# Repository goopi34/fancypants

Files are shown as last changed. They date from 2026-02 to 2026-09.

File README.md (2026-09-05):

# Fancypants


<br/>
A two-part system that uses an nRF52840 + VL53L0X time-of-flight sensor to control
sex toys through Intiface Engine. "Wave your hand" closer to the sensor for more
intensity, pull away to reduce it — or flip it around, or drive intensity by how
fast you're moving (see `mapping.mode` in [docs/middleware.md](docs/middleware.md)).

```mermaid
flowchart LR
    fw["<b>fancypants-nrf52</b><br/>Feather nRF52840<br/>+ VL53L0X sensor"]
    mw["<b>fancypants</b><br/>Rust middleware<br/>mapping + EMA"]
    engine["<b>Intiface Engine</b>"]
    toy(["toy"])
    fw -- "BLE<br/>range_mm + battery" --> mw
    mw -- "WebSocket<br/>intensity ScalarCmd" --> engine
    engine --> toy
```

## Quick start

Prebuilt binaries (firmware `.uf2` + Linux x86_64 middleware) are on the
[Releases page](../../releases) — download, flash, run. To build from source
you need `docker` (or `podman`) and `make`; everything builds in containers:

```bash
# 1. Build firmware + middleware
make

# 2. Flash the Feather: double-tap reset, then copy the UF2
#    (or `west flash` via SWD; `make flash` prints the details)
cp build/firmware/zephyr.uf2 /run/media/$USER/FTHR840BOOT/

# 3. Start Intiface Central with your toy connected, then run the middleware
#    (finds ./config.toml or ~/.config/fancypants/config.toml automatically,
#     and creates the latter on first run)
./build/middleware/fancypants
```

Move your hand near the sensor and enjoy.

## Documentation

- [Hardware & wiring](docs/hardware.md)
- [Building](docs/building.md) — build options, tests, manual (container-less) builds
- [Firmware](docs/firmware.md) — flashing, serial console, BLE protocol
- [Middleware](docs/middleware.md) — configuration, mapping modes, running
- [Troubleshooting](docs/troubleshooting.md)
- [Wearable design](wearable-design.md) — belt-mounted layout; printable
  enclosures in [enclosures/](enclosures/)

## License

MIT — see [LICENSE](LICENSE).

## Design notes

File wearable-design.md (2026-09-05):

# Fancypants Wearable Design Spec

## Overview

The fancypants hardware is worn as a belt-mounted system. The VL53L0X
rangefinder sits above the crotch facing outward, measuring the distance
to a partner's hand (or body). The Feather nRF52840 rides on the
hip opposite the belt clasp, powered by a 500mAh LiPo battery plugged directly into
the Feather's JST-PH connector.

## Layout

```
                  ┌─────────────┐
                  │  VL53L0X    │  ← sensor, facing outward
                  │  rangefinder│
                  └──────┬──────┘
                         │ I2C (4-wire: VIN, GND, SDA, SCL)
    ┌────────────────────┼────────────────────┐
    │                    │         BELT        │
    │  ┌──────────┐      │              ┌─────┐│
    │  │ Feather  │◄─────┘              │CLASP││
    │  │ nRF52840 │                     └─────┘│
    │  │ + LiPo   │                            │
    │  └──────────┘                            │
    └──────────────────────────────────────────┘
```

## Component Placement

### Belt

Standard belt or wide elastic waistband. The clasp sits on the right
hip (user's perspective, adjustable to preference). The belt carries
two components and the wiring between them.

### VL53L0X Sensor (front center)

- Mounted at belt line, centered above the crotch
- Sensor window faces directly outward (perpendicular to body)
- Field of view is 25° cone — aim straight out, not angled down
- Secured to belt with a small 3D-printed or sewn pouch
- Keep the sensor window unobstructed

### Feather nRF52840 + Battery (left hip)

- Mounted on the hip opposite the clasp
- Secured with a belt-mounted pouch, pocket, or velcro holster
- The BLE antenna is internal to the Feather — no external antenna
  needed, and the hip position gives decent range in all directions

## Power

The Feather is powered by an Adafruit 500mAh 3.7V LiPo battery
(product 1578, ~$8) plugged into the onboard JST-PH connector.

- Runtime: ~15 hours at typical draw (~30mA average with BLE +
  sensor polling)
- The battery and Feather are compact enough to share a single
  belt pouch
- The Feather's onboard charger handles recharging — just plug
  USB into the Feather. The yellow CHG LED lights during charge,
  goes off when complete. Charge time is ~5 hours from dead.
- When USB is connected, the Feather hot-swaps to USB power and
  charges the LiPo simultaneously

**Buy from Adafruit** (or verify JST-PH polarity matches Adafruit
convention). Cheap batteries from Amazon frequently have reversed
polarity and will destroy the Feather's charging circuit.

Link: https://www.adafruit.com/product/1578

## Wiring Run

The only wiring that runs along the belt is the I2C connection between
the Feather (left hip) and the VL53L0X (front center). This is 4 wires:

| Wire  | Color (STEMMA QT convention) | Notes |
|---|---|---|
| VIN | Red | 3.3V from Feather  |
| GND | Black | Ground |
| SDA | Blue | I2C data |
| SCL | Yellow | I2C clock |

Wire run is approximately 20-30cm depending on waist size. Options:

- **STEMMA QT cable**: Easiest. Adafruit sells 200mm and 300mm lengths.
  Plug directly into the VL53L0X breakout. Solder or use a STEMMA QT
  adapter on the Feather end.
- **Ribbon cable**: Low profile, can be sewn flat against the belt
  interior. 4-conductor ribbon or individual silicone wires.
- **Sewn channels**: For a cleaner look, sew a fabric channel along
  the belt interior and thread the wires through it.

I2C is tolerant of this wire length at 100kHz (the default). No
additional pullups or buffering needed beyond what the VL53L0X breakout
provides.

## Future Improvements

- 3D-printed enclosure that clips directly to belt

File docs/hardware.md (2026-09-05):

# Hardware

## Parts

- **Adafruit Feather nRF52840 Express**
- **Adafruit VL53L0X Time-of-Flight sensor breakout** (I2C, 30-1200mm range)
- **LiPo battery** (optional, JST-PH connector on Feather)
- Any Buttplug-compatible toy + Intiface Central

## Wiring

If your VL53L0X has a STEMMA QT / Qwiic connector, just use the cable.
Otherwise:

| Feather | VL53L0X |
|---|---|
| 3V | VIN |
| GND | GND |
| SDA | SDA |
| SCL | SCL |

The Adafruit VL53L0X breakout includes I2C pullups and a voltage regulator,
so no additional components are needed.

## Wearing it

See [wearable-design.md](../wearable-design.md) for the belt-mounted layout,
battery choice, and wiring run. Printable enclosures (OpenSCAD source +
exported STLs) live in [enclosures/](../enclosures/).

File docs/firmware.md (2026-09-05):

# Firmware (fancypants-nrf52)

## Flash

**UF2 method (no programmer needed):**

1. Connect Feather to USB
2. Double-tap the reset button — `FTHR840BOOT` drive appears
3. Copy the UF2 file:

```bash
cp build/firmware/zephyr.uf2 /run/media/$USER/FTHR840BOOT/
# (or wherever the drive mounts on your system)
```

**SWD method:**

```bash
west flash
```

## Verify

Connect to the USB serial console:

```bash
# Find the USB CDC ACM device
ls /dev/ttyACM*

# Connect (115200 baud, though CDC ACM ignores baud rate)
picocom /dev/ttyACM0
# or
screen /dev/ttyACM0 115200
```

You should see:

```
[00:00:00.000,000] <inf> main: Fancypants nRF52 0.1.4 starting...
[00:00:00.050,000] <inf> main: VL53L0X sensor ready
[00:00:00.060,000] <inf> battery: Battery ADC initialized on AIN5
[00:00:00.070,000] <inf> range_svc: Range Service initialized
[00:00:00.200,000] <inf> main: Bluetooth initialized
[00:00:00.210,000] <inf> main: Advertising as "Fancypants"
```

## BLE Protocol

**Custom Range Service UUID:** `00000001-7272-6e67-6669-6e6465720000`

| Characteristic | UUID | Properties | Data |
|---|---|---|---|
| Range | ...0002... | Read, Notify  | uint16_t LE, distance in mm |
| Config | ...0003... | Read, Write | 8-byte struct (see below) |

**Config struct (8 bytes, little-endian):**

| Offset | Type | Field |
|---|---|---|
| 0 | uint16_t | sample_interval_ms |
| 2 | uint16_t | notify_interval_ms |
| 4 | uint16_t | max_range_mm |
| 6 | uint16_t | min_range_mm |

Also exposes the standard **Battery Service (0x180F)**.

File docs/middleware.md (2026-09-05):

# Middleware (fancypants)

## Getting the binary

Either download the `fancypants-<version>-linux-x86_64.tar.gz` tarball from
the [Releases page](../../../releases) (binary + sample `config.toml`), or
build from source (see [building.md](building.md)) — the binary then lands in
`build/middleware/fancypants`.

## Prerequisites (runtime only)

- Linux (the only platform built and tested so far)
- Intiface Central running (https://intiface.com/#intiface-central)
- BlueZ

On Arch:

```bash
sudo pacman -S bluez bluez-utils
sudo systemctl enable --now bluetooth
```

## Configure

The middleware looks for its config in this order:

1. The path given with `-c PATH` (must exist)
2. `./config.toml` (current directory)
3. `$XDG_CONFIG_HOME/fancypants/config.toml` (usually `~/.config/fancypants/config.toml`)

If none is found, it writes a default config to
`~/.config/fancypants/config.toml`, prints where it put it, and runs with
those defaults — so on first run you get a commented config file to edit
without any extra steps. (The release tarball also ships a sample
`config.toml` next to the binary.)

`--generate-config` does the same thing explicitly (to `-c PATH` if given);
it refuses to overwrite an existing file.

```bash
# Edit as needed
$EDITOR ~/.config/fancypants/config.toml
```

Key settings:

- `mapping.mode` — what drives the intensity (see [Mapping modes](#mapping-modes))
- `mapping.invert = true` — closer = more intense (default, distance mode only)
- `mapping.min_range_mm` / `max_range_mm` — active zone
- `mapping.deadzone_mm` — pull away past this to turn off
- `mapping.smoothing` — 0.3 is a good default, increase for smoother response
- `ble.data_timeout_secs` — failsafe: if range data stops for this long, the toy
  is stopped and the middleware reconnects (0 disables)
- `buttplug.actuator_types` — which actuators to drive, with optional
  per-actuator settings (see below)

## Mapping modes

`mapping.mode` selects what the intensity follows:

- **`"distance"`** (default) — intensity follows the current reading, mapped
  across the `min_range_mm`–`max_range_mm` window. With `invert = true`
  closer means more intense; with `invert = false` further means more
  intense.
- **`"velocity"`** — intensity follows how *fast* the distance is changing,
  regardless of direction: wave or move quickly for more intensity, hold
  still for none. `max_speed_mm_s` sets the speed that maps to full
  intensity (default 500; slow hand movement is roughly 100-300mm/s, a fast
  wave ~1000mm/s). `invert` and the range window are ignored in this mode.

In both modes, readings beyond `deadzone_mm` produce zero intensity, and
`smoothing` applies to the result. In velocity mode a little extra smoothing
(0.4-0.6) helps, since speed estimates are inherently jumpier than distance
readings.

## Per-actuator configuration

Toys can have multiple actuators of different types (e.g. a vibrator plus an
oscillating arm). `buttplug.actuator_types` lists which types to drive; each
entry is either a plain type name or a table with per-actuator settings:

```toml
[buttplug]
server_address = "ws://127.0.0.1:12345"
actuator_types = [
    # Full-range vibration following the sensor
    "Vibrate",
    # Oscillation capped at 60%, pulsing on/off twice a second while active
    { type = "Oscillate", min_intensity = 0.2, max_intensity = 0.6, pattern = "pulse", pulse_hz = 2.0 },
]
```

Supported types: `Vibrate`, `Rotate`, `Oscillate`, `Constrict`, `Inflate`,
`Position`. Settings per actuator:

| Setting | Default | Meaning |
|---|---|---|
| `min_intensity` | 0.0 | Output when the mapped intensity is just above zero |
| `max_intensity` | 1.0 | Output when the mapped intensity is 1.0 |
| `pattern` | `constant` | `constant` follows the sensor; `pulse` gates it on/off |
| `pulse_hz` | 1.0 | Pulse frequency (only with `pattern = "pulse"`, max 10) |

Actuators on the toy whose type isn't listed are left off. If a toy has
several actuators of the same type, the nth entry of that type configures its
nth actuator, and extra actuators reuse the last entry of that type.

## Run

1. Start Intiface Central and ensure your toy is connected
2. Power on the Feather (USB or battery)
3. Run the middleware:

```bash
# Config is found automatically (./config.toml, then ~/.config/fancypants/)
./build/middleware/fancypants

# Or point at a specific config; with debug logging:
./build/middleware/fancypants -c myconfig.toml -l debug
```

## What happens

1. Middleware scans BLE for "Fancypants" device
2. Connects and subscribes to range notifications
3. Connects to Intiface Engine via websocket
4. Finds your toy
5. Maps distance → intensity and sends commands at ~20Hz

```
[INFO] Found device: Fancypants
[INFO] Connected to Intiface Engine at ws://127.0.0.1:12345
[INFO] Using device: We-Vibe Melt 2 (index 0)
[INFO] Running — move your hand near the sensor!
```

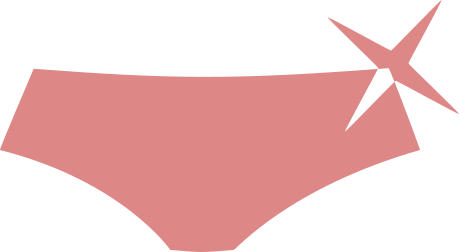
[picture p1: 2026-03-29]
fancypants.png

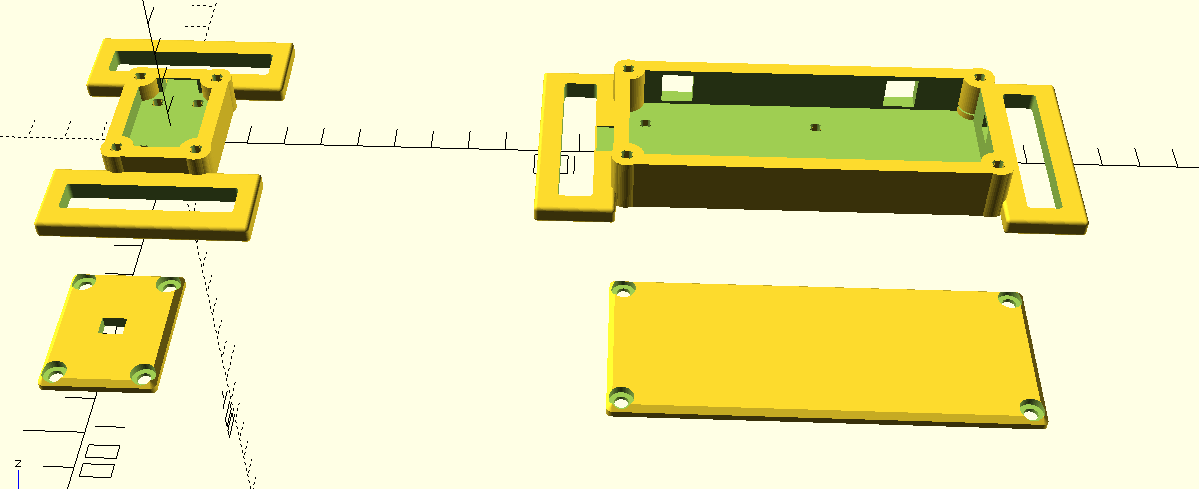
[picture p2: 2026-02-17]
enclosures/enclosures.png

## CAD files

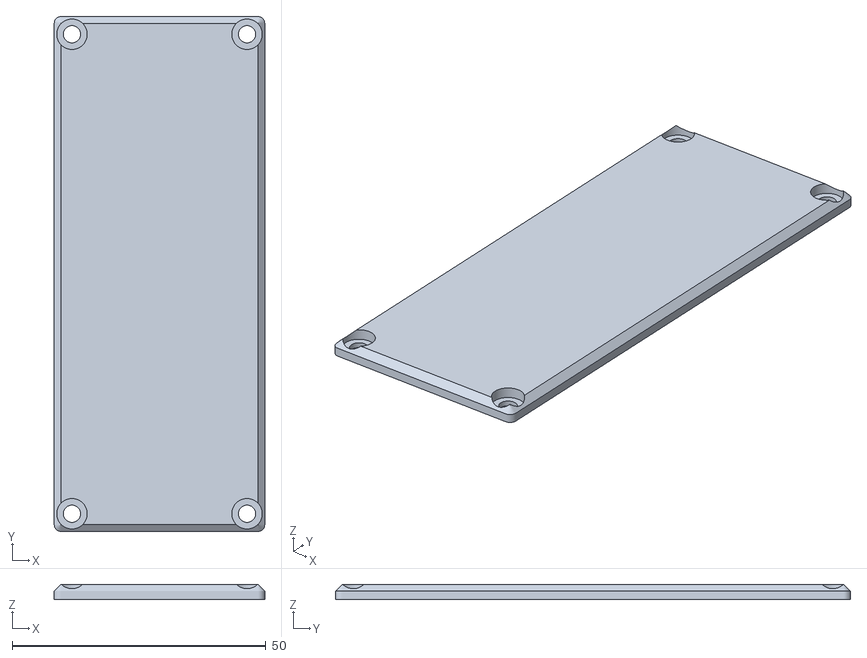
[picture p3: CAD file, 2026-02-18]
enclosures/hip_enclosure_top.stl
41.5 x 101.5 x 3.00

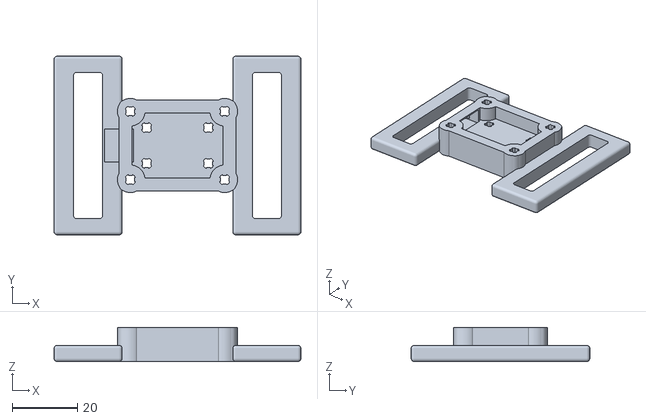
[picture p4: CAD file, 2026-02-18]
enclosures/front_enclosure_bottom.stl
76.0 x 55.0 x 10.5

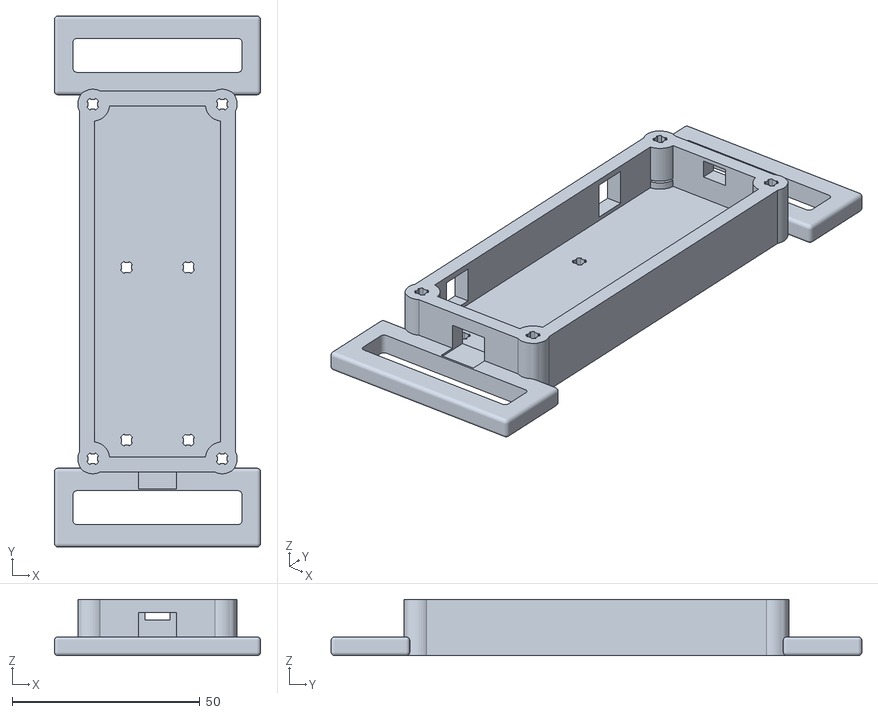
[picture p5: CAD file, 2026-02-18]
enclosures/hip_enclosure_bottom.stl
55.0 x 141.5 x 15.0

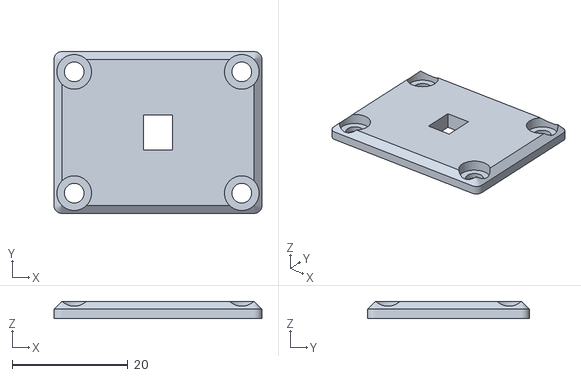
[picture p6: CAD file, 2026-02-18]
enclosures/front_enclosure_top.stl
36.0 x 28.0 x 3.00

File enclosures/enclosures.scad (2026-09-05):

// Belt-mounted wearable enclosure system for VL53L0X sensor + Feather nRF52840
// Two-part design: Front sensor enclosure + Hip controller enclosure
// Optimized for resin (DLP) printing

// ============================================================================
// GLOBAL PARAMETERS
// ============================================================================

$fn = 50;

// Common parameters
wall = 4;               // Wall thickness (resin-optimized)
clearance = 1.5;        // Component clearance
belt_width = 43;        // Belt width
belt_thickness = 7;     // Belt thickness at head
loop_clearance = 1;     // Extra clearance for belt in slots

// Screw boss parameters (3mm wood screws)
boss_od = 8;            // Outer diameter of screw boss (larger for ribbed interior)
boss_hole = 3.4;        // Oversized hole in boss (screw doesn't engage wall)
boss_rib_id = 2.6;      // Inner diameter at rib tips (screw bites into ribs)
boss_rib_count = 4;     // Number of grip ribs
boss_rib_width = 1.2;   // Angular width of each rib (mm at hole wall)
boss_clearance = 3.4;   // Clearance hole in lid for screw shaft
boss_counterbore_d = 6; // Counterbore diameter for screw head
boss_counterbore_depth = 2; // Counterbore depth in lid top

// Rounding
edge_r = 2;             // Fillet/round radius for edges and corners

// Belt tab parameters
tab_thickness = 5;      // Tab slab thickness
tab_wall = 5;           // Material bridge width flanking belt slot
tab_r = 1;              // Tab bottom edge rounding radius (kept small for printability)

// ============================================================================
// UTILITY MODULES
// ============================================================================

// Rounded rectangle 2D profile
module rounded_rect_2d(w, h, r) {
    offset(r) offset(-r) square([w, h], center=true);
}

// Box with rounded top edges only, perfectly flat bottom (for lids)
module rounded_box(w, h, d, r) {
    actual_r = min(r, d * 0.45);  // Clamp so it works for thin lids
    hull() {
        // Bottom: full-size rounded-corner rectangle, thin slab
        linear_extrude(height=0.01)
            rounded_rect_2d(w, h, actual_r);
        // Just below the top rounding: full-size
        translate([0, 0, d - actual_r])
            linear_extrude(height=0.01)
                rounded_rect_2d(w, h, actual_r);
        // Top: inset by actual_r on all sides, at full height
        translate([0, 0, d - 0.01])
            linear_extrude(height=0.01)
                rounded_rect_2d(w - 2*actual_r, h - 2*actual_r, 0.01);
    }
}

// Box with rounded vertical edges, flat top (for enclosure bodies)
module rounded_box_flat_top(w, h, d, r) {
    linear_extrude(height=d)
        rounded_rect_2d(w, h, r);
}

// Ribbed screw boss hole - oversized bore with inward ribs for thread grip
// Use in difference() to cut into a solid boss cylinder.
// Creates a hole_d bore with rib_count ribs protruding inward to rib_id.
module ribbed_boss_hole(hole_d, rib_id, rib_width, rib_count, h) {
    difference() {
        // Main oversized bore
        cylinder(d=hole_d, h=h);
        // Leave behind the ribs by subtracting the bore minus rib volumes
        // i.e., don't cut where the ribs are
        for(i = [0 : rib_count - 1]) {
            rotate([0, 0, i * (360 / rib_count)])
                translate([0, 0, -0.5])
                    linear_extrude(height=h + 1)
                        translate([rib_id/2, -rib_width/2])
                            square([(hole_d - rib_id)/2 + 0.1, rib_width]);
        }
    }
}

// Belt tab: rectangular body with ALL bottom edges and outer corners rounded
// Belt slot inner vertical edges also rounded for skin comfort
// Oriented: extends along +Y from origin, width along X
module belt_tab(tab_w, tab_l, tab_t, slot_w, slot_h, r) {
    difference() {
        // Start with a fully rounded shape via minkowski
        translate([0, tab_l/2, 0])
            minkowski() {
                translate([0, 0, tab_t/2])
                    cube([tab_w - 2*r, tab_l, tab_t - 2*r], center=true);
                sphere(r=r);
            }
        
        // Chop off the top dome - flatten to tab_t height
        translate([0, tab_l/2, tab_t + r + 0.5])
            cube([tab_w + 2*r + 1, tab_l + 2*r + 1, 2*r + 1], center=true);
        
        // Chop off everything below Z=0
        translate([0, tab_l/2, -(r + 0.5)])
            cube([tab_w + 2*r + 1, tab_l + 2*r + 1, 2*r + 1], center=true);
        
        // Belt slot - hull of 4 rounded-corner cylinders for rounded vertical edges
        hull() {
            for(x = [-1, 1]) {
                for(y = [-1, 1]) {
                    translate([x * (slot_w/2 - r), tab_l/2 + y * (slot_h/2 - r), -1])
                        cylinder(r=r, h=tab_t + 4);
                }
            }
        }
    }
}

// ============================================================================
// FRONT ENCLOSURE - VL53L0X SENSOR
// ============================================================================
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

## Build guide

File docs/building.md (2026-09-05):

# Building

Everything builds in containers — no local toolchains needed. Just `docker`
(or `podman`) and `make`.

```bash
# Build everything
make

# Build just firmware
make firmware

# Build just middleware
make middleware

# Clean all build artifacts
make clean

# See all options
make help
```

Build outputs land in `build/`:

```
build/
├── firmware/
│   └── zephyr.uf2          ← flash this to the Feather
├── middleware/
│   └── fancypants           ← run this on your PC
├── cargo-cache/             ← persistent Rust dependency cache
└── cargo-target/            ← persistent Rust build cache
```

## Build options

You can override the NCS version, board target, or container runtime:

```bash
make firmware NCS_TAG=v2.7-branch
make firmware BOARD=adafruit_feather_nrf52840/nrf52840/uf2
make CONTAINER=podman
```

For interactive debugging, drop into a build container shell:

```bash
make shell-fw    # firmware (NCS/Zephyr environment)
make shell-mw    # middleware (Rust environment)
```

## Tests and lint

```bash
make test        # middleware test suite
make lint        # rustfmt + clippy, clang-format
make coverage    # middleware coverage report (build/coverage/html/)
```

## Cutting a release

Pushing a `v*` tag triggers the release workflow
([.github/workflows/release.yml](../.github/workflows/release.yml)), which
runs the tests, builds both components, and publishes a GitHub Release with:

- `fancypants-nrf52-<version>.uf2` — firmware, ready to drag onto the
  `FTHR840BOOT` drive
- `fancypants-<version>-linux-x86_64.tar.gz` — middleware binary plus a
  commented sample `config.toml` and the docs

```bash
git tag v0.2.0
git push origin v0.2.0
```

The tag (minus the `v`) becomes the version embedded in both binaries.

## Manual builds (without containers)

If you'd rather install toolchains locally:

**Firmware** — requires nRF Connect SDK (`west`):

```bash
cd firmware
west build -b adafruit_feather_nrf52840
```

**Middleware** — requires Rust toolchain + BlueZ dev libs:

```bash
cd middleware
cargo build --release
```

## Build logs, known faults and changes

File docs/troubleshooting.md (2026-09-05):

# Troubleshooting

**"No Bluetooth adapters found"**
- `sudo systemctl start bluetooth`
- Check `rfkill list` for blocked adapters

**"Scan timeout: 'Fancypants' not found"**
- Is the Feather powered and running? Check USB serial console
- Is another device already connected to it? (nRF52840 supports 1 connection)
- Try `bluetoothctl` → `scan on` to verify the device is advertising

**"No Buttplug devices found"**
- Open Intiface Central, make sure it's running and your toy is visible
- Check that the websocket port matches `config.toml`

**Sensor stuck at 0mm or max range constantly**
- Check I2C wiring (SDA/SCL not swapped?)
- VL53L0X breakout getting 3.3V power?
- "Out of range" / no target reads are clamped by the firmware to
  `max_range_mm` (1200 by default), so a constant max reading usually
  just means nothing is in front of the sensor

**Jerky/stuttery toy response**
- Increase `mapping.smoothing` (try 0.5-0.7)
- Increase `notify_interval_ms` in firmware config characteristic
- In `mode = "velocity"`, some jitter is expected — speed estimates amplify
  sensor noise, so lean on smoothing more than in distance mode

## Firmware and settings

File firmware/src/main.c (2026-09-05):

/*
 * Fancypants nRF52 BLE Peripheral
 *
 * Reads distance from a VL53L0X time-of-flight sensor via I2C and
 * broadcasts it over BLE using a custom GATT service. Also reports
 * battery level via the standard Battery Service (BAS).
 *
 * Target: Adafruit Feather nRF52840 Express
 * Sensor: Adafruit VL53L0X breakout (I2C addr 0x29)
 *
 * BLE Services:
 *   - Custom Range Service (notify distance_mm + config)
 *   - Battery Service (BAS, standard)
 *   - Device Information Service (optional, via Kconfig)
 */

#include <zephyr/bluetooth/bluetooth.h>
#include <zephyr/bluetooth/gap.h>
#include <zephyr/bluetooth/gatt.h>
#include <zephyr/bluetooth/services/bas.h>
#include <zephyr/device.h>
#include <zephyr/drivers/sensor.h>
#include <zephyr/kernel.h>
#include <zephyr/logging/log.h>

#include "battery.h"
#include "range_service.h"

LOG_MODULE_REGISTER(main, LOG_LEVEL_INF);

/* VL53L0X device from devicetree */
static const struct device *range_sensor;

/* Connection state */
static struct bt_conn *current_conn;

/* Advertising data */
static const struct bt_data ad[] = {
    BT_DATA_BYTES(BT_DATA_FLAGS, (BT_LE_AD_GENERAL | BT_LE_AD_NO_BREDR)),
    BT_DATA_BYTES(BT_DATA_UUID128_ALL, RANGE_SERVICE_UUID_VAL),
};

/* Scan response - device name */
static const struct bt_data sd[] = {
    BT_DATA(BT_DATA_NAME_COMPLETE, CONFIG_BT_DEVICE_NAME, sizeof(CONFIG_BT_DEVICE_NAME) - 1),
};

/* BLE connection callbacks */
static void connected(struct bt_conn *conn, uint8_t err)
{
	if (err) {
		LOG_ERR("Connection failed (err %u)", err);
		return;
	}

	LOG_INF("Connected");
	current_conn = bt_conn_ref(conn);
}

static void disconnected(struct bt_conn *conn, uint8_t reason)
{
	LOG_INF("Disconnected (reason %u)", reason);

	if (current_conn) {
		bt_conn_unref(current_conn);
		current_conn = NULL;
	}

	/* Restart advertising */
	int err = bt_le_adv_start(BT_LE_ADV_CONN, ad, ARRAY_SIZE(ad), sd, ARRAY_SIZE(sd));
	if (err) {
		LOG_ERR("Advertising restart failed (err %d)", err);
	}
}

BT_CONN_CB_DEFINE(conn_callbacks) = {
    .connected = connected,
    .disconnected = disconnected,
};

/* Read VL53L0X and return distance in mm, or negative on error */
static int read_range_mm(void)
{
	struct sensor_value val;
	int ret;

	ret = sensor_sample_fetch(range_sensor);
	if (ret < 0) {
		LOG_WRN("Sensor fetch failed: %d", ret);
		return ret;
	}

	ret = sensor_channel_get(range_sensor, SENSOR_CHAN_DISTANCE, &val);
	if (ret < 0) {
		LOG_WRN("Sensor channel get failed: %d", ret);
		return ret;
	}

	/*
	 * Zephyr's VL53L0X driver returns distance in meters as
	 * a sensor_value (val1 = integer meters, val2 = fractional in
	 * millionths). Convert to mm.
	 */
	int distance_mm = val.val1 * 1000 + val.val2 / 1000;

	return distance_mm;
}

/* Sensor polling thread */
static void sensor_thread_fn(void *p1, void *p2, void *p3)
{
	ARG_UNUSED(p1);
	ARG_UNUSED(p2);
	ARG_UNUSED(p3);

	LOG_INF("Sensor thread started");

	while (1) {
		const struct range_config *cfg = range_service_get_config();

		int distance = read_range_mm();
		if (distance >= 0) {
			/* Clamp to configured range */
			uint16_t clamped = (uint16_t)distance;
			if (clamped < cfg->min_range_mm) {
				clamped = cfg->min_range_mm;
			}
			if (clamped > cfg->max_range_mm) {
				clamped = cfg->max_range_mm;
			}

			range_service_update(clamped);
		}

		k_msleep(cfg->sample_interval_ms);
	}
}

/* Battery monitoring thread */
static void battery_thread_fn(void *p1, void *p2, void *p3)
{
	ARG_UNUSED(p1);
	ARG_UNUSED(p2);
	ARG_UNUSED(p3);

	LOG_INF("Battery thread started");

	while (1) {
		int mv = battery_read_mv();
		if (mv > 0) {
			uint8_t pct = battery_mv_to_pct(mv);
			bt_bas_set_battery_level(pct);
			LOG_DBG("Battery: %dmV (%u%%)", mv, pct);
		}

		k_sleep(K_SECONDS(CONFIG_BATTERY_SAMPLE_INTERVAL_S));
	}
}

/* Thread stacks */
K_THREAD_STACK_DEFINE(sensor_stack, 2048);
K_THREAD_STACK_DEFINE(battery_stack, 1024);

static struct k_thread sensor_thread;
static struct k_thread battery_thread;

int main(void)
{
	int err;

	LOG_INF("Fancypants nRF52 %s starting...", CONFIG_APP_VERSION_STRING);

	/* Get VL53L0X device */
	range_sensor = DEVICE_DT_GET_ONE(st_vl53l0x);
	if (!device_is_ready(range_sensor)) {
		LOG_ERR("VL53L0X sensor not ready");
		return -ENODEV;
	}
	LOG_INF("VL53L0X sensor ready");

	/* Initialize battery ADC */
	err = battery_init();
	if (err) {
		LOG_WRN("Battery init failed: %d (continuing without battery)", err);
	}

	/* Initialize custom range service */
	err = range_service_init();
	if (err) {
		LOG_ERR("Range service init failed: %d", err);
		return err;
	}

	/* Enable Bluetooth */
	err = bt_enable(NULL);
	if (err) {
		LOG_ERR("Bluetooth init failed: %d", err);
		return err;
	}
	LOG_INF("Bluetooth initialized");

	/* Start advertising */
	err = bt_le_adv_start(BT_LE_ADV_CONN, ad, ARRAY_SIZE(ad), sd, ARRAY_SIZE(sd));
	if (err) {
		LOG_ERR("Advertising failed to start: %d", err);
		return err;
	}
	LOG_INF("Advertising as \"%s\"", CONFIG_BT_DEVICE_NAME);

	/* Spawn worker threads */
	k_thread_create(&sensor_thread, sensor_stack, K_THREAD_STACK_SIZEOF(sensor_stack),
			sensor_thread_fn, NULL, NULL, NULL, K_PRIO_COOP(7), 0, K_NO_WAIT);
	k_thread_name_set(&sensor_thread, "sensor");

	k_thread_create(&battery_thread, battery_stack, K_THREAD_STACK_SIZEOF(battery_stack),
			battery_thread_fn, NULL, NULL, NULL, K_PRIO_PREEMPT(10), 0, K_NO_WAIT);
	k_thread_name_set(&battery_thread, "battery");

	LOG_INF("Fancypants nRF52 running");

	return 0;
}

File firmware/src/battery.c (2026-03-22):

#include "battery.h"

#include <zephyr/drivers/adc.h>
#include <zephyr/kernel.h>
#include <zephyr/logging/log.h>

LOG_MODULE_REGISTER(battery, LOG_LEVEL_INF);

/*
 * Adafruit Feather nRF52840 has a voltage divider on the VBAT pin:
 *   VBAT --- [100K] --- ADC (P0.29, AIN5) --- [100K] --- GND
 *
 * So ADC reads VBAT / 2. We need to multiply by 2 to get actual voltage.
 * nRF52840 ADC internal reference = 0.6V, gain 1/6 = 3.6V full scale.
 */

#define ADC_RESOLUTION 12
#define ADC_GAIN ADC_GAIN_1_6
#define ADC_REFERENCE ADC_REF_INTERNAL /* 0.6V */
#define ADC_CHANNEL 5		       /* AIN5 = P0.29 */
#define DIVIDER_RATIO 2		       /* VBAT/2 resistor divider */

/* Full scale voltage in mV: 0.6V * 6 (gain) = 3.6V = 3600mV */
#define ADC_FULL_SCALE_MV 3600

static const struct device *adc_dev;
static int16_t adc_buffer;

static struct adc_channel_cfg channel_cfg = {
    .gain = ADC_GAIN,
    .reference = ADC_REFERENCE,
    .acquisition_time = ADC_ACQ_TIME(ADC_ACQ_TIME_MICROSECONDS, 40),
    .channel_id = ADC_CHANNEL,
#if defined(CONFIG_ADC_NRFX_SAADC)
    .input_positive = SAADC_CH_PSELP_PSELP_AnalogInput5,
#endif
};

static struct adc_sequence sequence = {
    .channels = BIT(ADC_CHANNEL),
    .buffer = &adc_buffer,
    .buffer_size = sizeof(adc_buffer),
    .resolution = ADC_RESOLUTION,
};

int battery_init(void)
{
	adc_dev = DEVICE_DT_GET(DT_NODELABEL(adc));
	if (!device_is_ready(adc_dev)) {
		LOG_ERR("ADC device not ready");
		return -ENODEV;
	}

	int ret = adc_channel_setup(adc_dev, &channel_cfg);
	if (ret < 0) {
		LOG_ERR("ADC channel setup failed: %d", ret);
		return ret;
	}

	LOG_INF("Battery ADC initialized on AIN%d", ADC_CHANNEL);
	return 0;
}

int battery_read_mv(void)
{
	int ret = adc_read(adc_dev, &sequence);
	if (ret < 0) {
		LOG_ERR("ADC read failed: %d", ret);
		return ret;
	}

	/* Convert raw ADC to millivolts */
	int32_t mv = adc_buffer;

	/* Handle negative values from SAADC offset */
	if (mv < 0) {
		mv = 0;
	}

	/* Scale: (raw / 4096) * 3600mV * 2 (divider) */
	mv = (mv * ADC_FULL_SCALE_MV * DIVIDER_RATIO) / (1 << ADC_RESOLUTION);

	return (int)mv;
}

uint8_t battery_mv_to_pct(int mv)
{
	/* LiPo discharge curve approximation (single-cell 3.7V nominal) */
	if (mv >= 4200) {
		return 100;
	} else if (mv >= 4100) {
		/* 4200-4100: 100-90% */
		return 90 + (mv - 4100) * 10 / 100;
	} else if (mv >= 3800) {
		/* 4100-3800: 90-50% */
		return 50 + (mv - 3800) * 40 / 300;
	} else if (mv >= 3600) {
		/* 3800-3600: 50-20% */
		return 20 + (mv - 3600) * 30 / 200;
	} else if (mv >= 3300) {
		/* 3600-3300: 20-0% */
		return (mv - 3300) * 20 / 300;
	} else {
		return 0;
	}
}

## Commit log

2026-02-15 Add enclosure OpenSCAD scripts
    [enclosures.scad]
2026-02-16 Update IR enclosure to include window
    [enclosures.scad]
2026-02-16 Add image of enclosures
2026-02-17 Update enclosure and export stl
    [enclosures.scad, enclosures.stl]
2026-02-17 Improve model printability
    [enclosures.scad, enclosures.stl, front_enclosure_bottom.stl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]
2026-02-17 Fix the mounting screw holes
    [enclosures.scad, front_enclosure_bottom.stl, front_enclosure_top.stl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]
2026-02-18 Correct stl exporter script
    [front_enclosure_bottom.stl, front_enclosure_top.stl, hip_enclosure_bottom.stl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]
2026-03-22 Bring middleware test coverage from ~10% to 82% (#14)
    Add 71 unit tests across all middleware modules, extracting testable
    logic from hardware-coupled code via trait abstractions (ToyBackend,
    DeviceHandle, AsyncSessionFn) and pure function extraction
    (parse_notification, process_notifications, find_range_characteristic,
    intensity_changed, load_config, reconnect_loop, run_session_inner).
    Coverage by file: config.rs 100%, mapper.rs 100%, ble.rs 74%,
    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
2026-09-05 Per-actuator control, velocity mapping mode, config auto-setup, docs restructure, and release pipeline (#17)
    * Include fancypants logos
    * Adjust logo format in README
    * Update image formatting
    * Address review findings, split docs, add mapping modes and release pipeline
    - Trim README to overview/quick-start/license; move details to docs/
    - Replace ASCII architecture diagram with Mermaid
    - Add mapping.mode = "distance" | "velocity" (intensity from rate of range
    change, normalized by max_speed_mm_s) alongside the existing invert option
    - Config UX: search ./config.toml then XDG path; auto-generate a default
    config on first run; --generate-config refuses to overwrite
    - Add tag-triggered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
    [enclosures.scad]
2026-11-13 Add multi-toy support, BLE config/battery wiring, and firmware fixes (#18)
2026-11-14 Wire Android MainActivity BLE permissions, droidplug Java classes, and foreground service (#24)
2026-11-14 Update documentation to reflect current project state (#27)
